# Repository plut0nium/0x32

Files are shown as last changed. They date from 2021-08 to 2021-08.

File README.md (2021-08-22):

# >**0x32**_ "Brussels Waffle". Lighter & Crispier. 
A 40% low-profile & wireless ortholinear board ⌨

> **Warning / Disclaimer**  
> These files are provided as a reference for designing keyboard PCBs, without liability and without any guarantees regarding functionality. 
> Although prototypes have been built and tested, errors may still be present.
> It is not advised to use them in your own project without electronics knowledge.

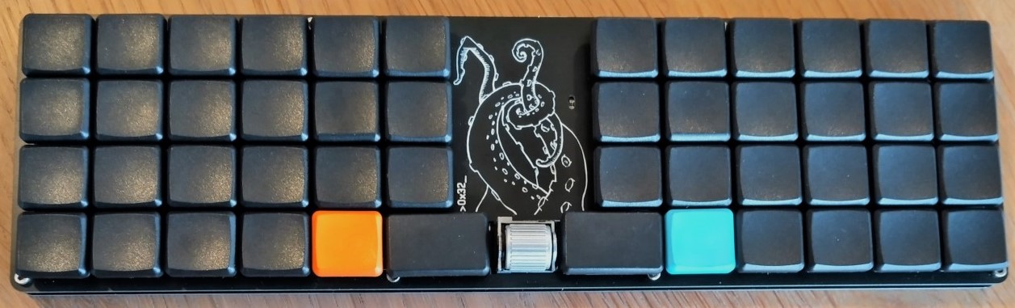
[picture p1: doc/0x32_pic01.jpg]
0x32 Picture

More pictures: <https://imgur.com/a/yrJpx6d>

## Features

 * Powered by nRF52840 SoC
   * 32bit, 64MHz, 1Mo flash
   * Bluetooth 5.0
 * Advanced LiPo battery charging circuit (_see comments below_)
 * USB Type-C with ESD protection
 * Designed for Kailh PG1350 "Choc" switches
   * Uses the smaller choc 18×17mm pitch
   * Only 1u alphas & mods (+ 1.5 or 2u split spacebar)
 * Supports 1 centered (thumb) roller encoder 
 * Powered by ZMK

## Comments / Design discussion

The battery and power management circuitry was designed around the following ICs:

 * BQ24075 for LiPo charging
 * TPS63031 for (3.3V) voltage regulation

This can be considered as a relatively advanced design, in comparison with the "classical" TP4056 + DW01A + LDO combination, but is also far from perfect:

This was taken as a learning opportunity, and performance improvement (in terms of power efficiency), if any, has not been assessed, and is probably not worth the extra cost and design complexity.
This is especially true for the use of a Buck-Boost converter, as the gain in extra power recovery from the battery should be limited (to max 5% capacity wrt a simpler Buck, or even a good quality LDO linear regulator).

I would however always recommend the use of high-quality components when it comes to LiPo battery management...

Other design limitations:
 * The lack of a LED tied to an IO of the MCU module, making it impossible to (externally) identify when the device is in bootloader mode.
 * The two available LEDs are used for power management / battery charging are sandwiched between the PCB and the switch plate, thus not replaceable once the board is assembled.

No PCBA files are provided since the few proto boards were assembled by hand (human PnP and reflow oven).

## Battery

The cutout in the PCB has been designed to accomodate a **402535** LiPo battery (~300mAh), sandwiched between switch & bottom plates.

## Layout

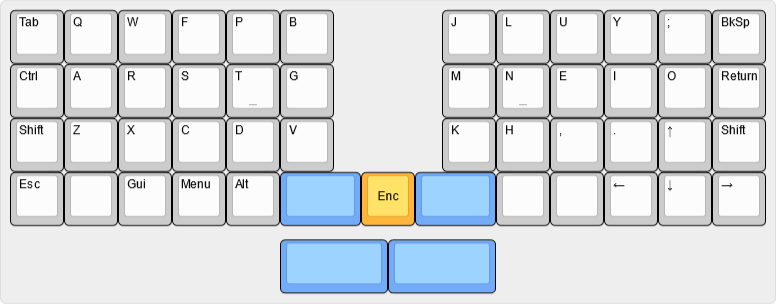
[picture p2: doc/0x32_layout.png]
0x32 Layout


## License

Copyright Charles Fourneau, 2021.

This source describes Open Hardware and is licensed under the _CERN-OHL-W_ v2

You may redistribute and modify this documentation and make products using it under the terms   of the CERN-OHL-W v2 (<https:/cern.ch/cern-ohl>). This documentation is distributed WITHOUT ANY EXPRESS OR IMPLIED WARRANTY, INCLUDING OF MERCHANTABILITY, SATISFACTORY QUALITY AND FITNESS FOR A PARTICULAR PURPOSE. Please see the CERN-OHL-W v2 for applicable conditions.

## Credits

0x32 is a new design but inspired by boards like:
 - Hadron by Ishtob
 - Boardwalk by AlexAtPanc, Shensmobile & others
 - Planck (Light) by OLKB
 - Pancake by Spaceman
 - ...some if my previous designs 😄

And special thanks to [ebastler](https://github.com/ebastler) for providing information I used as reference design for Holyiot modules.

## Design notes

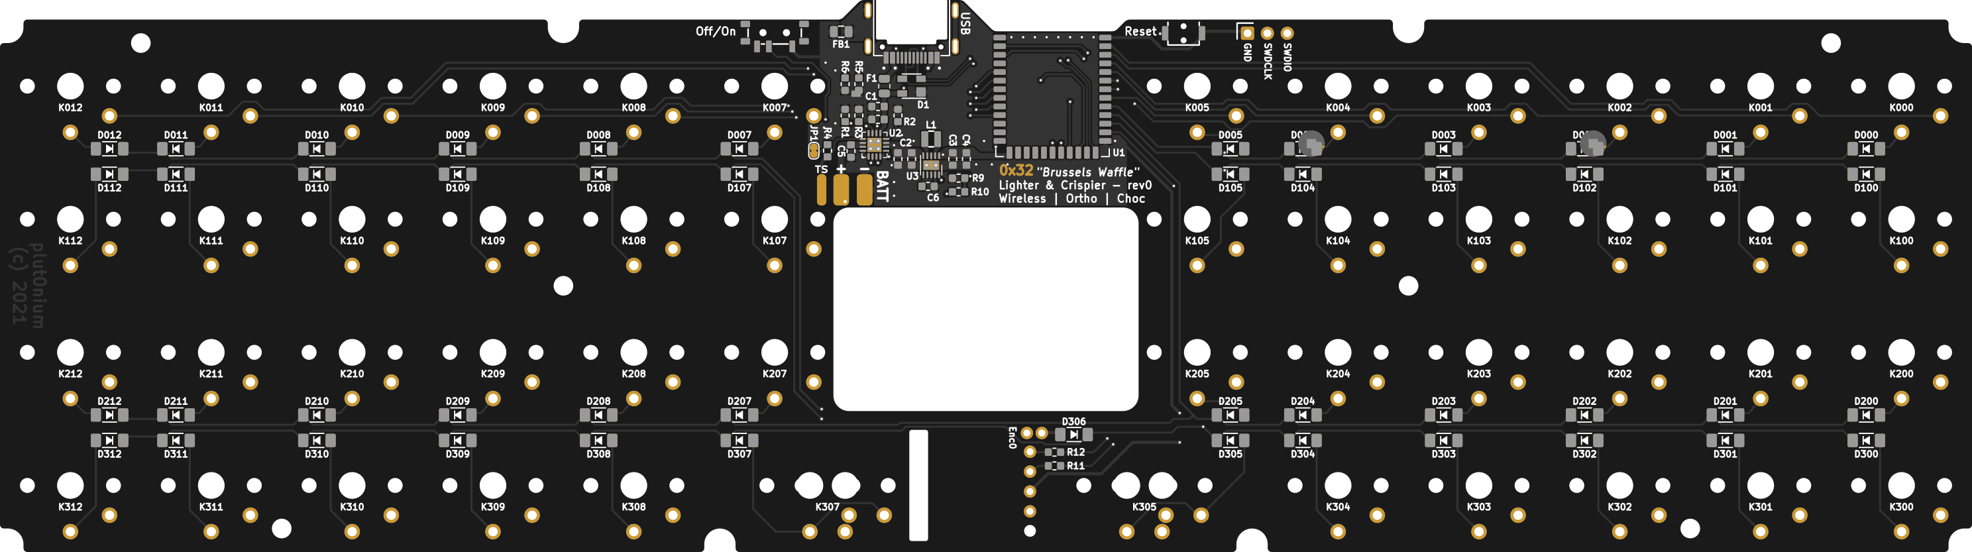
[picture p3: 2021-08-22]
doc/0x32_bottom.png

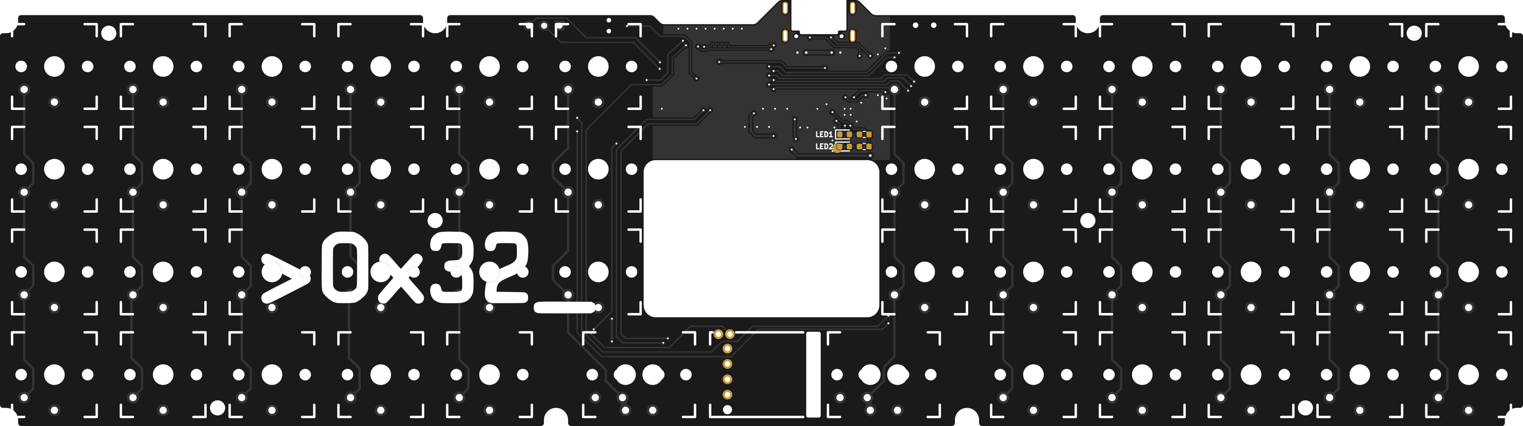
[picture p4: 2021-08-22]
doc/0x32_top.png

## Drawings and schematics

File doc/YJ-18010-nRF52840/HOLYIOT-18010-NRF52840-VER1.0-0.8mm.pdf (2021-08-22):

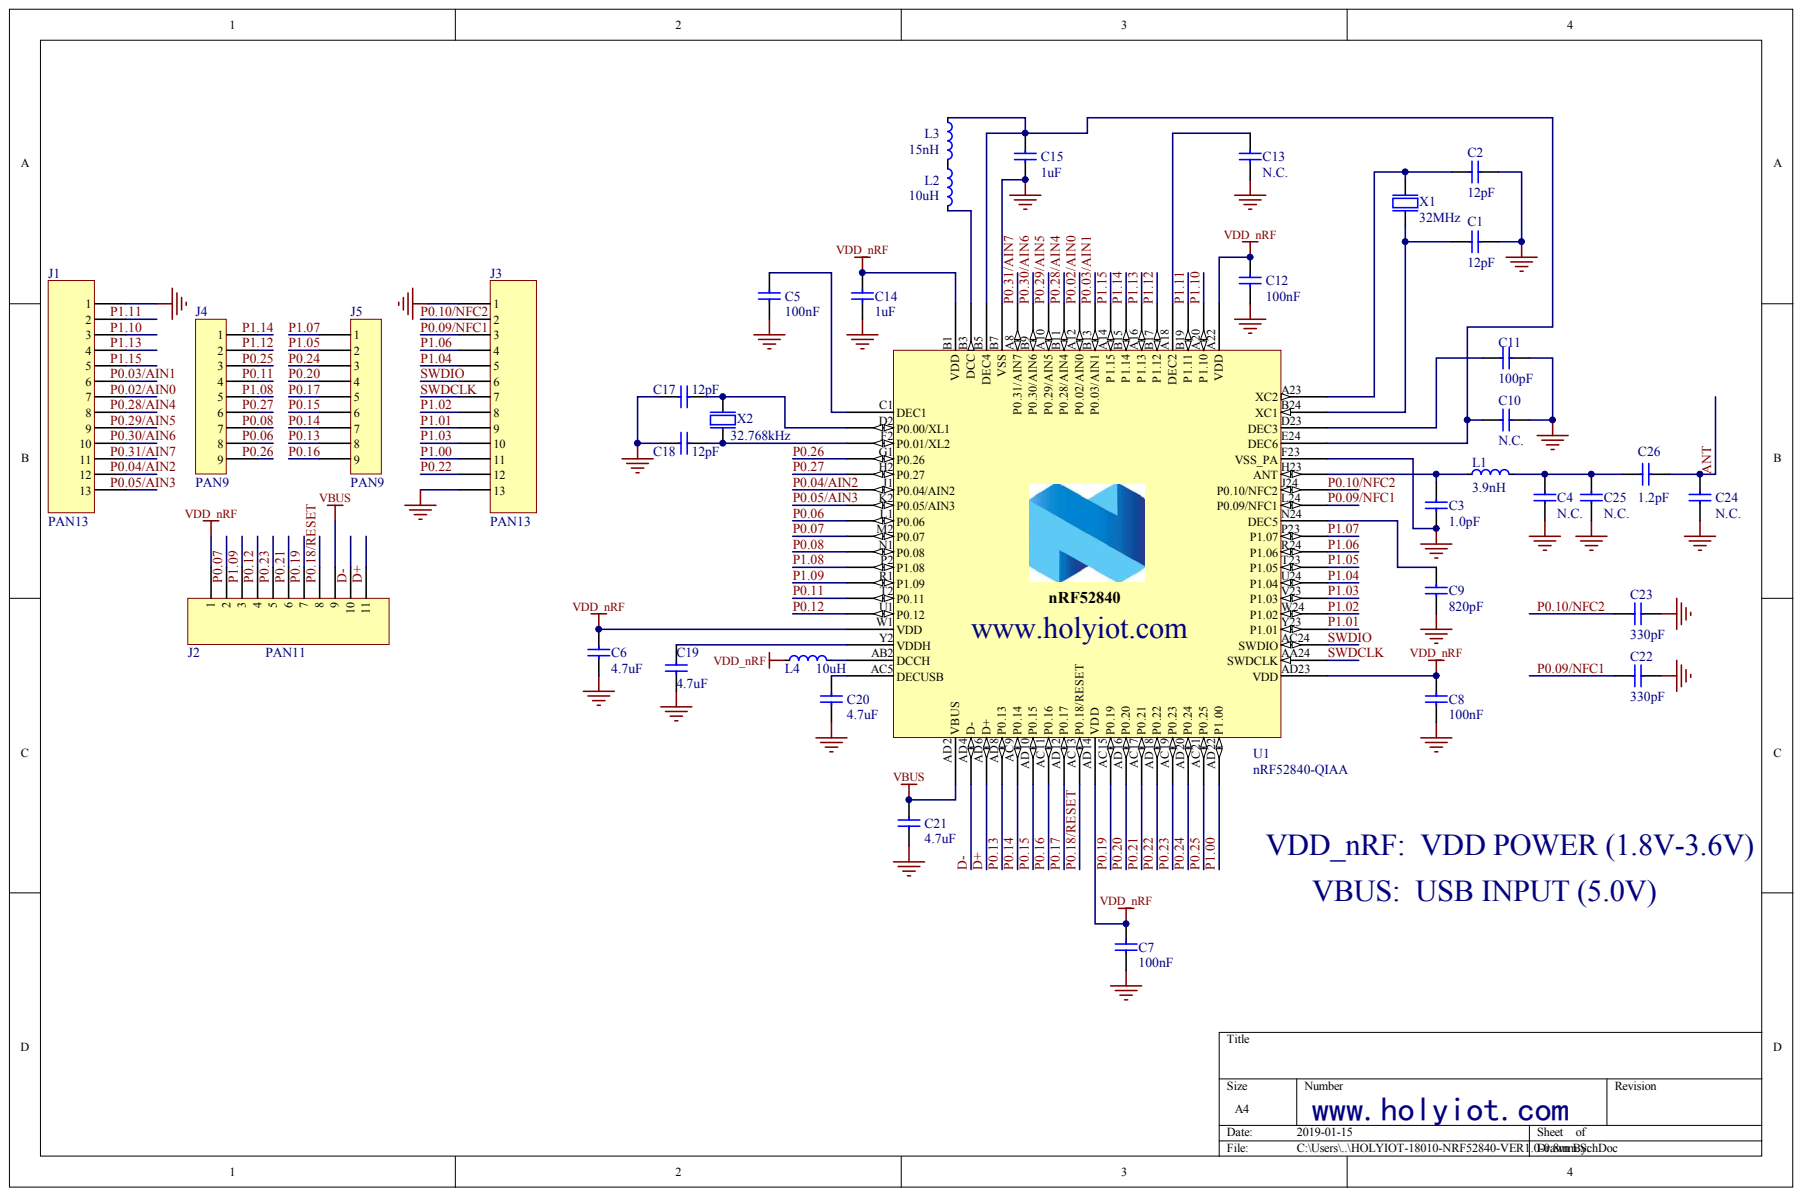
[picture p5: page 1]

P1.1 2 P1.0 5 | P1.0 6
P0.2 5 P0.2 4 | P1.0 4
P0.1 1 P0.2 0 | S WDIO
P1.0 8 P0.1 7 | S WDCL K
P0.2 7 P0.1 5 | P1.0 2

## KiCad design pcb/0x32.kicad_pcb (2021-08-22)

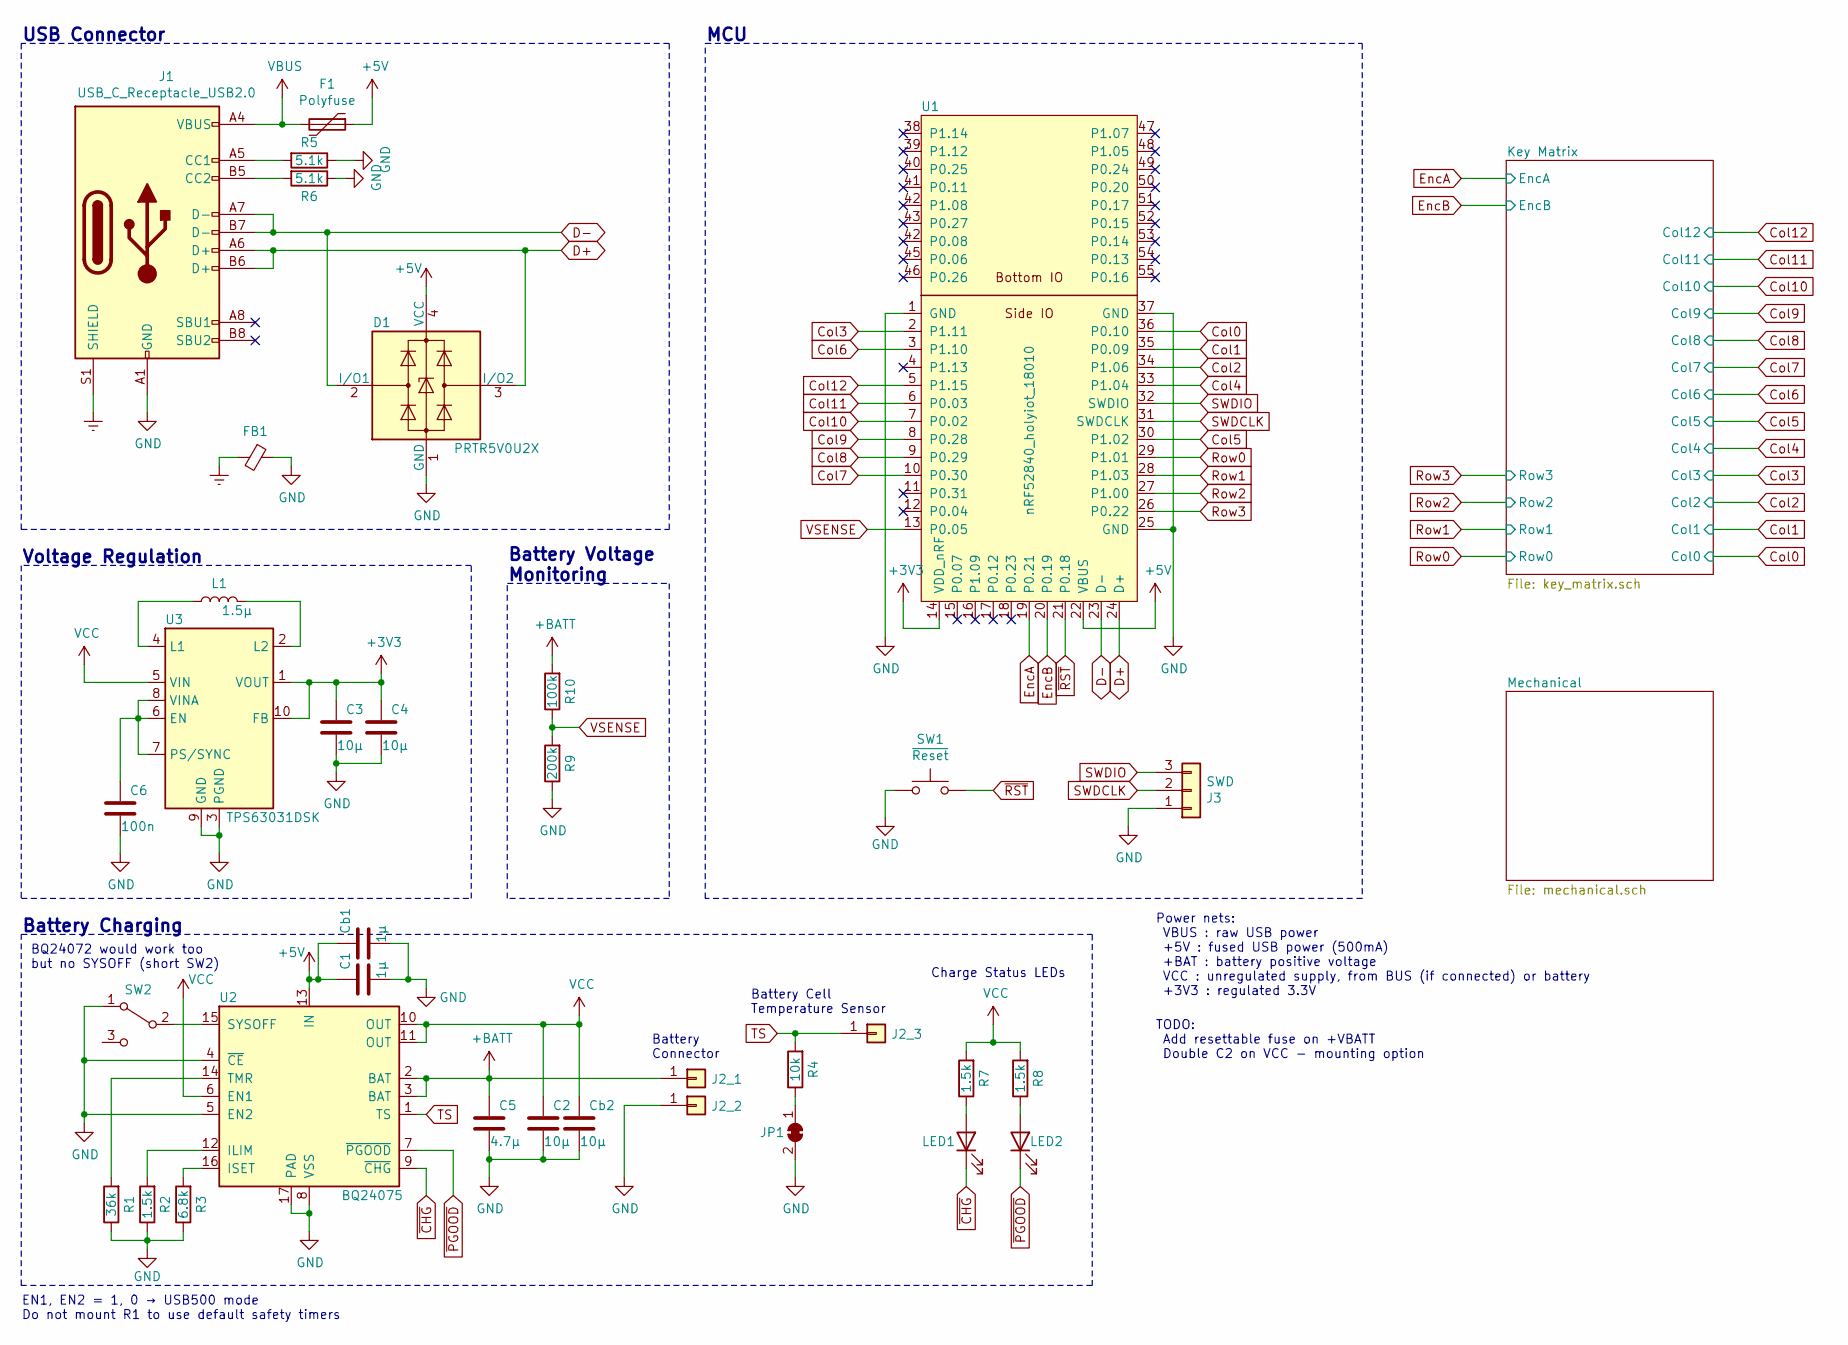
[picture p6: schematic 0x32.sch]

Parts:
C1: 1µ; C_0603_1608Metric; LCSC C29823
C2, C3, C4: 10µ; C_0603_1608Metric; LCSC C29823
C5: 4.7µ; C_0603_1608Metric; LCSC C29823
C6: 100n; C_0603_1608Metric; LCSC C29823
Cb1: 1µ; C_0603_1608Metric; LCSC C29823
Cb2: 10µ; C_0603_1608Metric; LCSC C29823
D1: PRTR5V0U2X; SOT-143; LCSC C78442
F1: Polyfuse; Fuse_0805_2012Metric; LCSC C135338
FB1: Ferrite_Bead_Small; R_0805_2012Metric
J1: USB_C_Receptacle_USB2.0; USB_C_Receptacle_HRO_TYPE-C-31-M-14
J2_1, J2_2, J2_3: Conn_01x01; SolderPad_4.0x2.0mm
J3: SWD; PinHeader_1x03_P2.54mm_Vertical
JP1: SolderJumper_2_Bridged; SolderJumper-2_RoundedPad_0.8x1.0mm
L1: 1.5µ; L_1008_2520Metric
LED1, LED2: LED; LED_0603_1608Metric
R1: 36k; R_0603_1608Metric; LCSC C23186
R2, R7, R8: 1.5k; R_0603_1608Metric; LCSC C23186
R3: 6.8k; R_0603_1608Metric; LCSC C23186
R4: 10k; R_0603_1608Metric; LCSC C23186
R5, R6: 5.1k; R_0603_1608Metric; LCSC C23186
R9: 200k; R_0603_1608Metric; LCSC C23186
R10: 100k; R_0603_1608Metric; LCSC C23186
SW1: ~Reset; TS-1186E-X-A; LCSC C318884
SW2: SW_SPDT; SW_SPDT_SMD_PCM12
U1: nRF52840_holyiot_18010; nRF52840_holyiot_18010_SideOnly
U2: BQ24075; VQFN-16-1EP_3x3mm_P0.5mm_EP1.8x1.8mm
U3: TPS63031DSK; WSON-10-1EP_2.5x2.5mm_P0.5mm_EP1.2x2mm

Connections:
+3V3: C3.1, C4.1, U1.14 (VDD_nRF), U3.1 (VOUT), U3.10 (FB)
+5V: C1.1, Cb1.1, D1.4 (VCC), F1.1, U1.22 (VBUS), U2.13 (IN)
+BATT: C5.1, J2_1.1, R10.2, U2.2 (BAT), U2.3 (BAT)
Col0: U1.36 (P0.10); also elsewhere on the board
Col1: U1.35 (P0.09); also elsewhere on the board
Col2: U1.34 (P1.06); also elsewhere on the board
Col3: U1.2 (P1.11); also elsewhere on the board
Col4: U1.33 (P1.04); also elsewhere on the board
Col5: U1.30 (P1.02); also elsewhere on the board
Col6: U1.3 (P1.10); also elsewhere on the board
Col7: U1.10 (P0.30); also elsewhere on the board
Col8: U1.9 (P0.29); also elsewhere on the board
Col9: U1.8 (P0.28); also elsewhere on the board
Col10: U1.7 (P0.02); also elsewhere on the board
Col11: U1.6 (P0.03); also elsewhere on the board
Col12: U1.5 (P1.15); also elsewhere on the board
D+: D1.3 (I/O2), J1.A6 (D+), J1.B6 (D+), U1.24 (D+)
D-: D1.2 (I/O1), J1.A7 (D-), J1.B7 (D-), U1.23 (D-)
Earth: FB1.2, J1.S1 (SHIELD)
EncA: U1.19 (P0.21); also elsewhere on the board
EncB: U1.20 (P0.19); also elsewhere on the board
GND: C1.2, C2.2, C3.2, C4.2, C5.2, C6.2, Cb1.2, Cb2.2, D1.1 (GND), FB1.1, J1.A1 (GND), J1.A12 (GND), J1.B1 (GND), J1.B12 (GND), J2_2.1, J3.1, JP1.2 (B), R1.1, R2.1, R3.1, R5.1, R6.1, R9.1, SW1.1, SW2.1 (A), U1.1 (GND), U1.25 (GND), U1.37 (GND), U2.4 (~CE), U2.5 (EN2), U2.8 (VSS), U2.17 (PAD), U3.3 (PGND), U3.9 (GND), U3.11 (PGND); also elsewhere on the board
unnamed: C6.1, U3.6 (EN), U3.7 (PS/SYNC), U3.8 (VINA)
unnamed: J1.A5 (CC1), R5.2
unnamed: J1.B5 (CC2), R6.2
unnamed: JP1.1 (A), R4.1
unnamed: L1.1, U3.4 (L1)
unnamed: L1.2, U3.2 (L2)
unnamed: LED1.2 (A), R7.1
unnamed: LED2.2 (A), R8.1
unnamed: R1.2, U2.14 (TMR)
unnamed: R2.2, U2.12 (ILIM)
unnamed: R3.2, U2.16 (ISET)
unnamed: SW2.2 (B), U2.15 (SYSOFF)
Row0: U1.29 (P1.01); also elsewhere on the board
Row1: U1.28 (P1.03); also elsewhere on the board
Row2: U1.27 (P1.00); also elsewhere on the board
Row3: U1.26 (P0.22); also elsewhere on the board
SWDCLK: J3.2, U1.31 (SWDCLK)
SWDIO: J3.3, U1.32 (SWDIO)
TS: J2_3.1, R4.2, U2.1 (TS)
VBUS: F1.2, J1.A4 (VBUS), J1.A9 (VBUS), J1.B4 (VBUS), J1.B9 (VBUS)
VCC: C2.1, Cb2.1, R7.2, R8.2, U2.6 (EN1), U2.10 (OUT), U2.11 (OUT), U3.5 (VIN)
VSENSE: R9.2, R10.1, U1.13 (P0.05)
~CHG: LED1.1 (K), U2.9 (~CHG)
~PGOOD: LED2.1 (K), U2.7 (~PGOOD)
~RST: SW1.2, U1.21 (P0.18)

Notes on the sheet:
Battery Charging
Voltage Regulation
USB Connector
Power nets: VBUS : raw USB power +5V : fused USB power (500mA) +BAT : battery positive voltage VCC : unregulated supply, from BUS (if connected) or battery +3V3 : regulated 3.3V
Battery Cell Temperature Sensor
Charge Status LEDs
Battery Voltage Monitoring
MCU
BQ24072 would work too but no SYSOFF (short SW2)
TODO: Add resettable fuse on +VBATT Double C2 on VCC - mounting option
Battery Connector
EN1, EN2 = 1, 0 → USB500 mode Do not mount R1 to use default safety timers

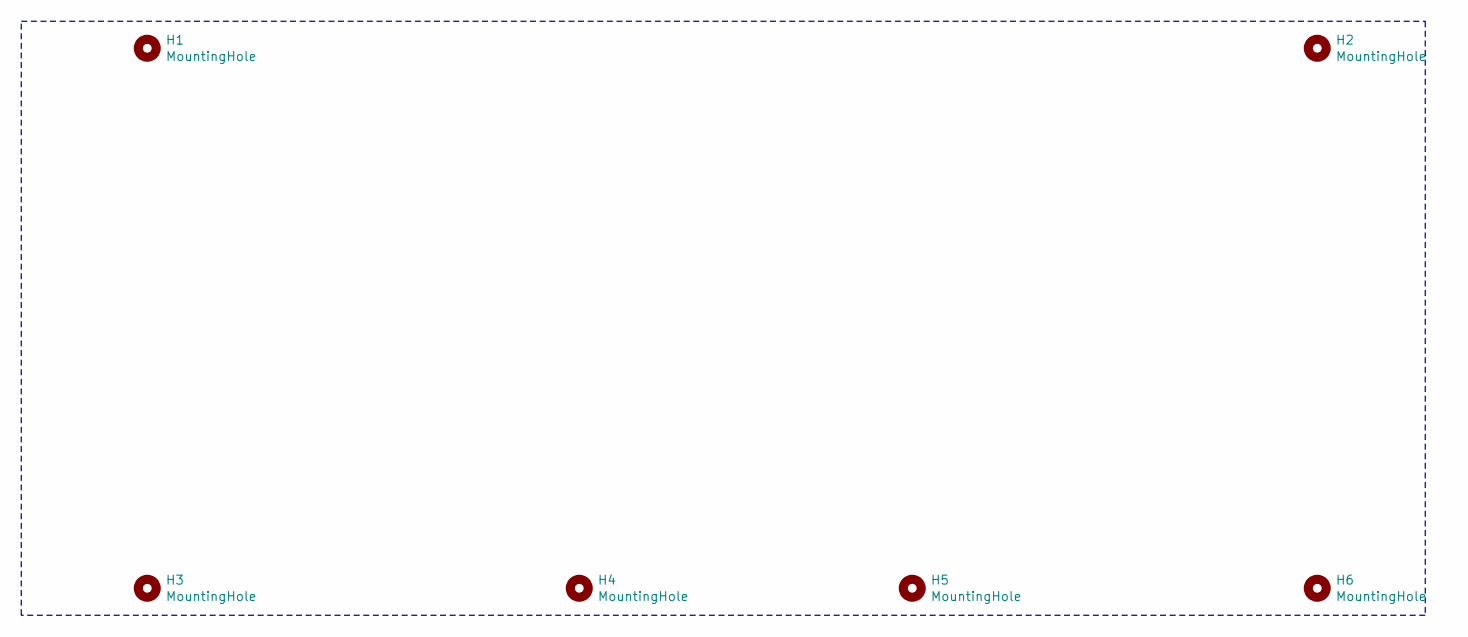
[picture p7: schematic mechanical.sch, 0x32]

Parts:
H1, H2, H3, H4, H5, H6: MountingHole; MountingHole_2.5mm

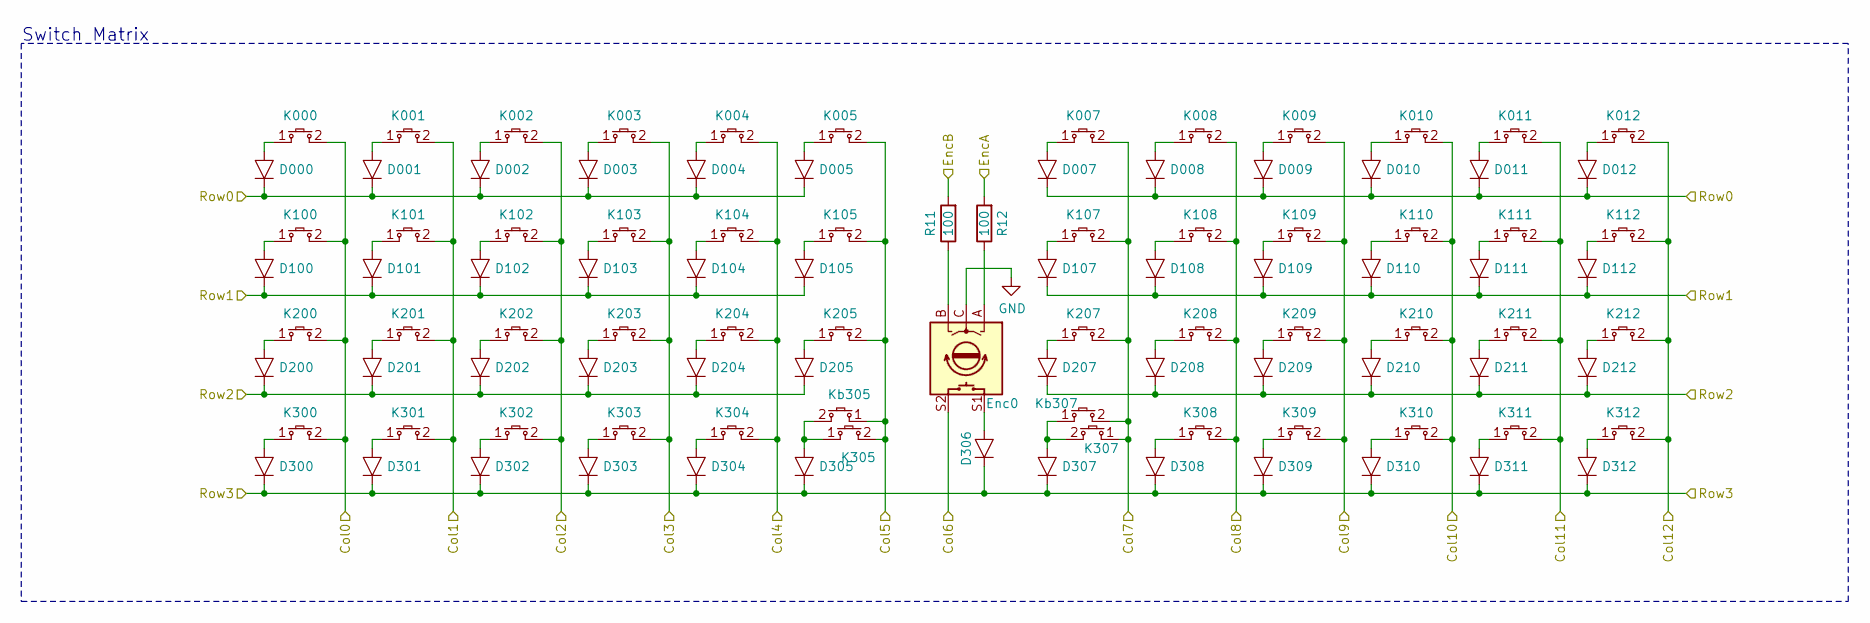
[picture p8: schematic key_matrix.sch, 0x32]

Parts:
D000, D001, D002, D003, D004, D005, D007, D008, D009, D010, D011, D012, D100, D101, D102, D103, D104, D105, D107, D108, D109, D110, D111, D112, D200, D201, D202, D203, D204, D205, D207, D208, D209, D210, D211, D212, D300, D301, D302, D303, D304, D305, D307, D308, D309, D310, D311, D312: Diode; D_MiniMELF
D306: Diode; D_MiniMELF; LCSC C2128
Enc0: Rotary_Encoder_Switch; RollerEncoder_Panasonic_EVQWGD001
K000, K001, K002, K003, K004, K005, K007, K008, K009, K010, K011, K012, K100, K101, K102, K103, K104, K105, K107, K108, K109, K110, K111, K112, K200, K201, K202, K203, K204, K205, K207, K208, K209, K210, K211, K212, K300, K301, K302, K303, K304, K308, K309, K310, K311, K312: Key_Switch; Kailh_PG1350_Choc-1U-NoLED
K305, K307: Key_Switch; Kailh_PG1350_Choc-2U-NoLED
Kb305, Kb307: Key_Switch; Kailh_PG1350_Choc-1.5U-NoLED
R11, R12: 100; R_0603_1608Metric

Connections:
Col0: K000.2, K100.2, K200.2, K300.2; also elsewhere on the board
Col1: K001.2, K101.2, K201.2, K301.2; also elsewhere on the board
Col2: K002.2, K102.2, K202.2, K302.2; also elsewhere on the board
Col3: K003.2, K103.2, K203.2, K303.2; also elsewhere on the board
Col4: K004.2, K104.2, K204.2, K304.2; also elsewhere on the board
Col5: K005.2, K105.2, K205.2, K305.2, Kb305.1; also elsewhere on the board
Col6: Enc0.S2; also elsewhere on the board
Col7: K007.2, K107.2, K207.2, K307.1, Kb307.2; also elsewhere on the board
Col8: K008.2, K108.2, K208.2, K308.2; also elsewhere on the board
Col9: K009.2, K109.2, K209.2, K309.2; also elsewhere on the board
Col10: K010.2, K110.2, K210.2, K310.2; also elsewhere on the board
Col11: K011.2, K111.2, K211.2, K311.2; also elsewhere on the board
Col12: K012.2, K112.2, K212.2, K312.2; also elsewhere on the board
EncA: R12.2; also elsewhere on the board
EncB: R11.2; also elsewhere on the board
GND: Enc0.C; also elsewhere on the board
unnamed: D000.2 (A), K000.1
unnamed: D001.2 (A), K001.1
unnamed: D002.2 (A), K002.1
unnamed: D003.2 (A), K003.1
unnamed: D004.2 (A), K004.1
unnamed: D005.2 (A), K005.1
unnamed: D007.2 (A), K007.1
unnamed: D008.2 (A), K008.1
unnamed: D009.2 (A), K009.1
unnamed: D010.2 (A), K010.1
unnamed: D011.2 (A), K011.1
unnamed: D012.2 (A), K012.1
unnamed: D100.2 (A), K100.1
unnamed: D101.2 (A), K101.1
unnamed: D102.2 (A), K102.1
unnamed: D103.2 (A), K103.1
unnamed: D104.2 (A), K104.1
unnamed: D105.2 (A), K105.1
unnamed: D107.2 (A), K107.1
unnamed: D108.2 (A), K108.1
unnamed: D109.2 (A), K109.1
unnamed: D110.2 (A), K110.1
unnamed: D111.2 (A), K111.1
unnamed: D112.2 (A), K112.1
unnamed: D200.2 (A), K200.1
unnamed: D201.2 (A), K201.1
unnamed: D202.2 (A), K202.1
unnamed: D203.2 (A), K203.1
unnamed: D204.2 (A), K204.1
unnamed: D205.2 (A), K205.1
unnamed: D207.2 (A), K207.1
unnamed: D208.2 (A), K208.1
unnamed: D209.2 (A), K209.1
unnamed: D210.2 (A), K210.1
unnamed: D211.2 (A), K211.1
unnamed: D212.2 (A), K212.1
unnamed: D300.2 (A), K300.1
unnamed: D301.2 (A), K301.1
unnamed: D302.2 (A), K302.1
unnamed: D303.2 (A), K303.1
unnamed: D304.2 (A), K304.1
unnamed: D305.2 (A), K305.1, Kb305.2
unnamed: D306.2 (A), Enc0.S1
unnamed: D307.2 (A), K307.2, Kb307.1
unnamed: D308.2 (A), K308.1
unnamed: D309.2 (A), K309.1
unnamed: D310.2 (A), K310.1
unnamed: D311.2 (A), K311.1
unnamed: D312.2 (A), K312.1
unnamed: Enc0.A, R12.1
unnamed: Enc0.B, R11.1
Row0: D000.1 (K), D001.1 (K), D002.1 (K), D003.1 (K), D004.1 (K), D005.1 (K), D007.1 (K), D008.1 (K), D009.1 (K), D010.1 (K), D011.1 (K), D012.1 (K); also elsewhere on the board
Row1: D100.1 (K), D101.1 (K), D102.1 (K), D103.1 (K), D104.1 (K), D105.1 (K), D107.1 (K), D108.1 (K), D109.1 (K), D110.1 (K), D111.1 (K), D112.1 (K); also elsewhere on the board
Row2: D200.1 (K), D201.1 (K), D202.1 (K), D203.1 (K), D204.1 (K), D205.1 (K), D207.1 (K), D208.1 (K), D209.1 (K), D210.1 (K), D211.1 (K), D212.1 (K); also elsewhere on the board
Row3: D300.1 (K), D301.1 (K), D302.1 (K), D303.1 (K), D304.1 (K), D305.1 (K), D306.1 (K), D307.1 (K), D308.1 (K), D309.1 (K), D310.1 (K), D311.1 (K), D312.1 (K); also elsewhere on the board

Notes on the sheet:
Switch Matrix

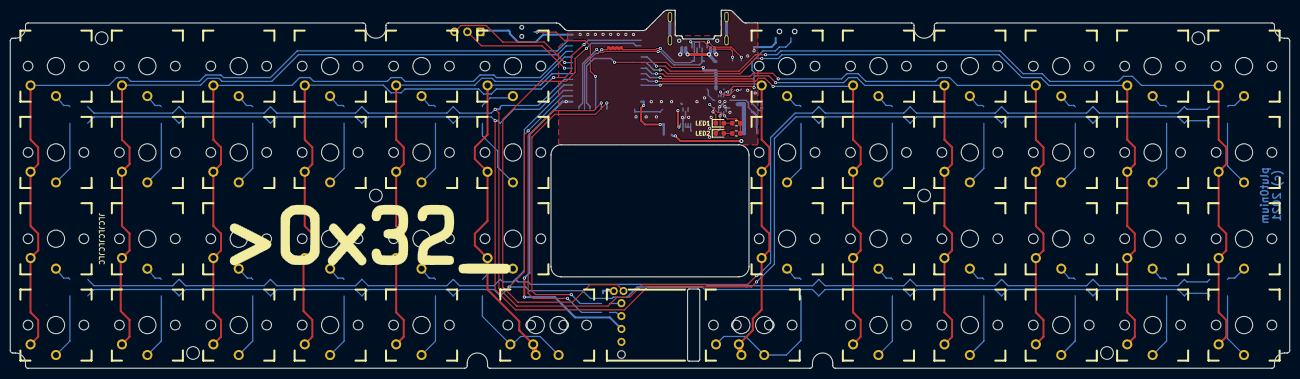
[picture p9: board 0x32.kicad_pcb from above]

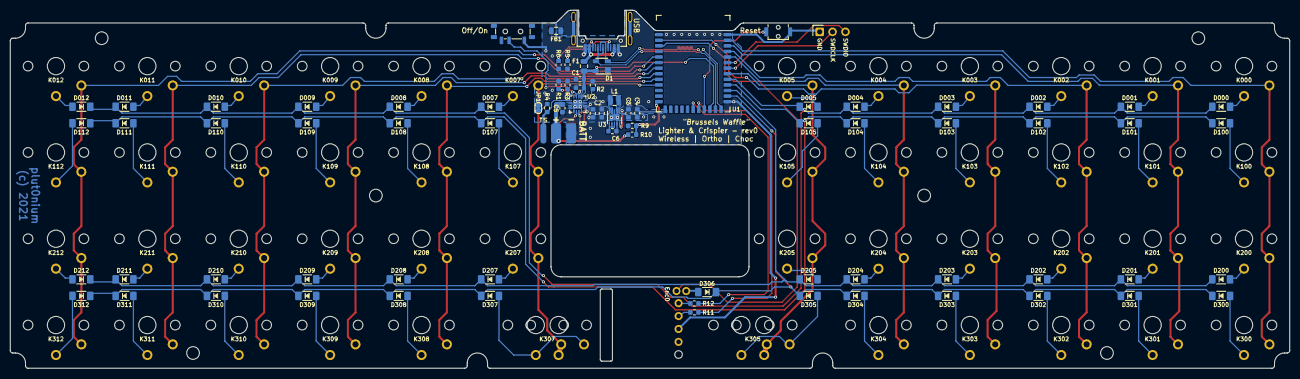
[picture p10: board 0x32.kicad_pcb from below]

Board: 2 copper layers, 252.0 x 70.5 mm, 143 parts (82 on the bottom side), 98 nets.

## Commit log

2021-08-22 0x32 Final PCB - rev0
    [0x32.kicad_pcb, 0x32.sch, HOLYIOT-18010-VER1.0-0.8MM.PcbLib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]
2021-08-22 Add BOM for human PnP
2021-08-22 Add (clean) switch and bottom plates
    [0x32_bottom_plate.kicad_pcb, 0x32_switch_plate.kicad_pcb]

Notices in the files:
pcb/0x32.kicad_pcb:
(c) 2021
